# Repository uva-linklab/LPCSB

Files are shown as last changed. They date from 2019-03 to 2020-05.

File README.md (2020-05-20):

# LPCSB
LPCSB = Low Power Color Sensing Board

The LPCSB is designed to measure the ambient light in the surrounding area by means of a TCS34725 Color Sensor.  The sensor uses four analog-to-digital converters (ADCs) to read four photodiodes (one photodiode per ADC).  The photodiodes are red-filtered, green-filtered, blue-filtered, and clear (no filter).  The photodiodes are also covered with an IR-blocking filter.  The code in the "software" folder of this repository is responsible for initializing all of the hardware on the LPCSB, configuring the settings of the color sensor (integration time, gain, enabling the internal oscillator, enabling the ADCs, and setting a hardware interrupt in the sensor), reading and saving the values taken by the four ADCs mentioned previously, and then calculating the the temperature of each color (how much of each is in the sample taken), as well as the lux (intensity per square meter) of said sample.  The measured color temperatures along with the calculated values are broadcast through the BLE radio built into the nrf51822 processor used in this board several times, with new measurements being taken every five seconds.  

There is also a data-processing algorithm that is meant to operate on a desktop computer, using  a Bluetooth receiver - see thesis for the specific one - to capture the transmitted data from the LPCSB and save it to an Excel spreadsheet.  Depending on the version of the algorithm being used, it can also classify the type of light measured by the LPCSB before saving the data to Excel.  When running tests with the LPCSB, make sure that the algorithm is running BEFORE activating the LPCSB to avoid errors with the algorithm in its current state.

SIDE NOTE:  Make sure that the external crystal oscillator meets the BLE chip requirements for the external clock frequency described in the nrf51822 datasheet. In this case, the required frequency for the external clock is 16 MHz.  For some reason, the clock chips that were being used early on were 26 MHz clocks instead of 16 MHz, which WILL cause errors with whichever sections of the processor happen to rely on the external signal (in this case, the BLE Radio parts).

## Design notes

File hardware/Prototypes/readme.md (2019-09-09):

# Version 1:

The files in this folder hold prototype schematics for potential additions for the LPCSB (layout and schematic files).

Label the prototype files as follows: LPCSB_Color_[insert new sensor name here]_[board or schematic]

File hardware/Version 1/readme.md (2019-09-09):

# Version 1:

The files in this folder hold the current hardware schematics for the LPCSB (layout and schematic files).

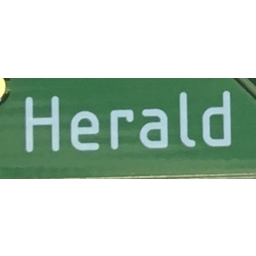
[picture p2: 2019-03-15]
summon/LPCSB/img/herald.png

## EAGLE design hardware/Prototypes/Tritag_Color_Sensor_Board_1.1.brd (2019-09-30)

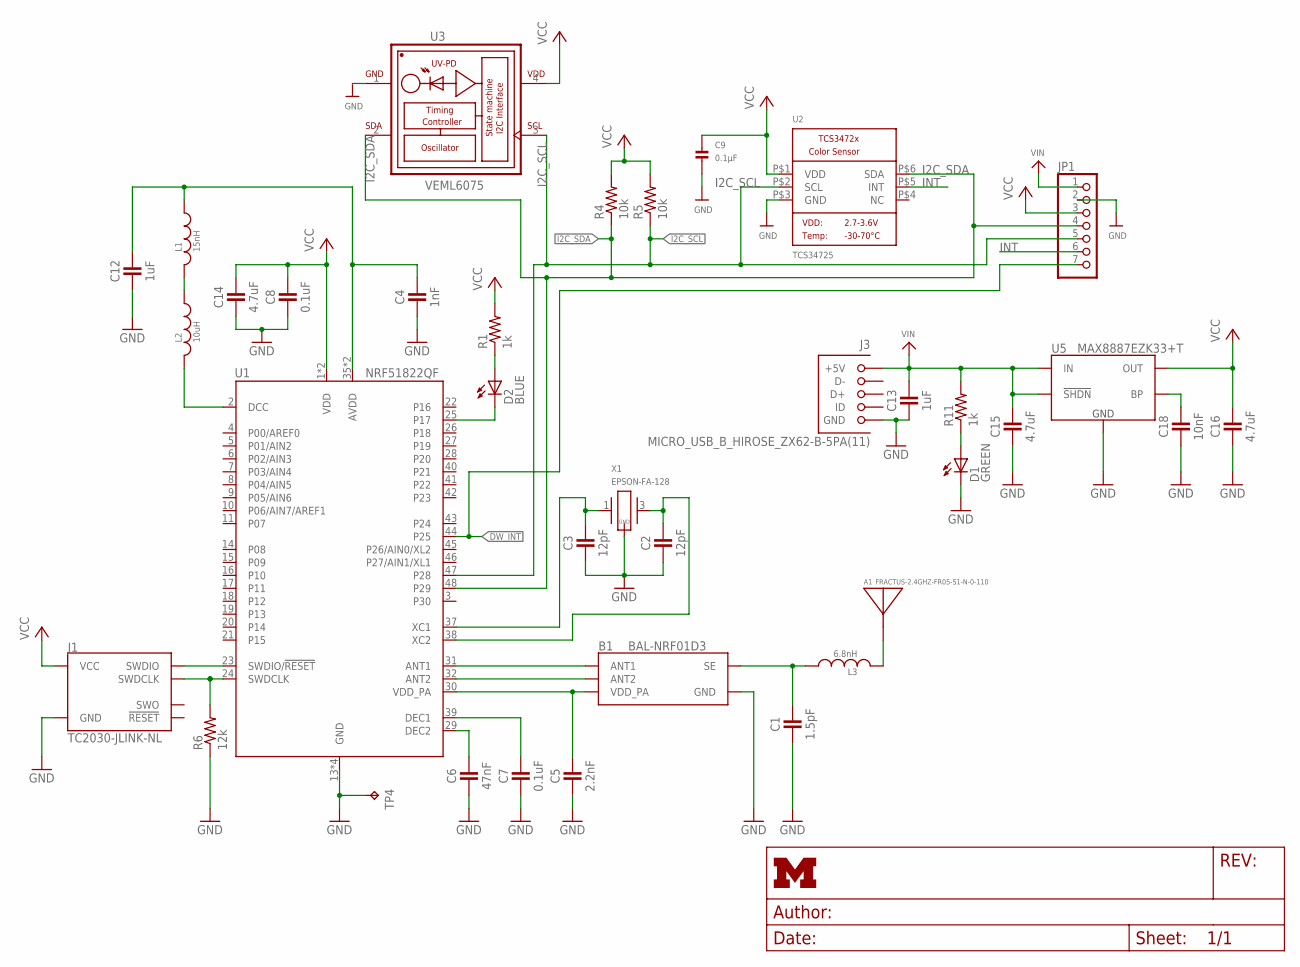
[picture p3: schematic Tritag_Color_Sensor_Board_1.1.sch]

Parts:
A1: FRACTUS-2.4GHZ-FR05-S1-N-0-110; FRACTUS-ANTENNA-FR05-S1-N-0-110
B1: BAL-NRF01D3
C1: 1.5pF; 0402_CAP
C2, C3: 12pF; 0402_CAP
C4: 1nF; 0402_CAP
C5: 2.2nF; 0402_CAP
C6: 47nF; 0402_CAP
C7, C8: 0.1uF; 0402_CAP
C9: 0.1µF; _0805
C12, C13: 1uF; 0402_CAP
C14, C15, C16: 4.7uF; 0402_CAP
C18: 10nF; 0402_CAP
D1: GREEN; LED-0603
D2: BLUE; LED-0603
J1: TC2030-JLINK-NL; TC2030-IDC-NL
J3: MICRO_USB_B_HIROSE_ZX62-B-5PA(11); USB_MICRO_B-HIROSE-ZX62-B-5PA(11)
JP1: HEADER-1X770MIL; 1X07_ROUND_70
L1: 15nH; 0402_CAP
L2: 10uH; 0603_CAP
L3: 6.8nH; 0402_CAP
R1, R11: 1k; 0402_RES
R4, R5: 10k; 0402_RES
R6: 12k; 0402_RES
TP4: TPTP06SQ; TP06SQ
U1: NRF51822QF; QFN-48-6MM
U2: TCS34725; TCS3472_FN6
U3: VEML6075; VISHAY_VEML6075_1.25X2X1
U5: MAX8887EZK33+T; SOT-23-5
X1: EPSON-FA-128; FA-128

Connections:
!CHRG: D1.A, R11.1
!CHRG1: D2.A, R1.1
ANTENNA: A1.ANT, L3.2
AVDD: C4.1, C12.1, L1.1, U1.35 (AVDD), U1.36 (AVDD)
DCC: L2.2, U1.2 (DCC)
DW_INT: JP1.7, U1.44 (P25)
GND: B1.GND, C1.2, C2.2, C3.2, C4.2, C5.2, C6.2, C7.2, C8.2, C9.2, C12.2, C13.2, C14.2, C15.2, C16.2, C18.2, D1.C, J1.5 (GND), J3.5 (GND), JP1.2, R6.1, TP4.TP, U1.13 (GND), U1.33 (GND), U1.34 (GND), U1.GND, U2.P$3 (GND), U3.1 (GND), U5.2 (GND), X1.2 (GND), X1.4 (GND)
I2C_SCL: JP1.5, R5.1, U1.47 (P28), U2.P$2 (SCL), U3.3 (SCL)
I2C_SDA: JP1.4, R4.1, U1.48 (P29), U2.P$6 (SDA), U3.2 (SDA)
INT: JP1.6, U2.P$5 (INT)
unnamed: B1.SE, C1.1, L3.1
unnamed: D2.C, U1.25 (P17)
unnamed: C3.1, U1.37 (XC1), X1.1
unnamed: C2.1, U1.38 (XC2), X1.3 (2)
unnamed: C18.1, U5.4 (BP)
unnamed: C6.1, U1.29 (DEC2)
unnamed: C7.1, U1.39 (DEC1)
unnamed: B1.ANT1, U1.31 (ANT1)
unnamed: B1.ANT2, U1.32 (ANT2)
unnamed: B1.VCC (VDD_PA), C5.1, U1.30 (VDD_PA)
unnamed: L1.2, L2.1
SWDCLK: J1.4 (SWDCLK), R6.2, U1.24 (SWDCLK)
SWDIO/!RESET: J1.2 (SWDIO), U1.23 (SWDIO/!RESET)
VCC: C8.1, C9.1, C14.1, C16.1, J1.1 (VCC), JP1.3, R1.2, R4.2, R5.2, U1.1 (VDD), U1.12 (VDD), U2.P$1 (VDD), U3.4 (VDD), U5.5 (OUT)
VIN: C13.1, C15.1, J3.1 (+5V), JP1.1, R11.2, U5.1 (IN), U5.3 (!SHDN)

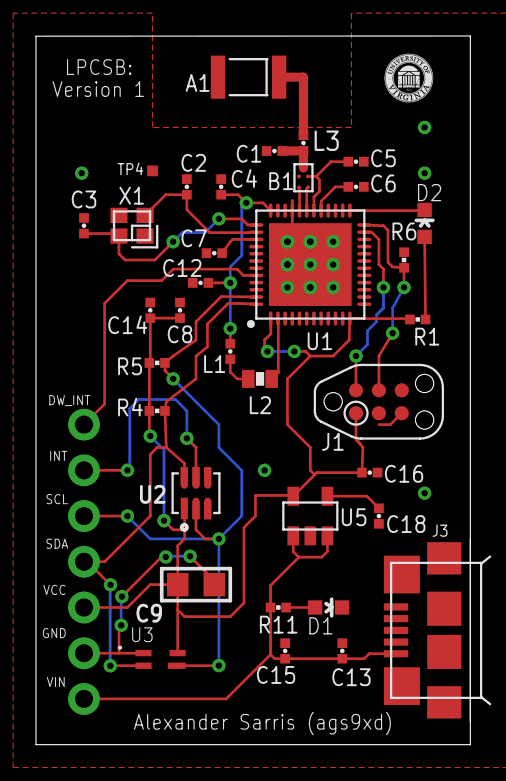
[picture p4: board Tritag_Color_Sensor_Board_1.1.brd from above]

Board: 2 copper layers, 24.1 x 39.4 mm, 36 parts (0 on the bottom side), 25 nets.

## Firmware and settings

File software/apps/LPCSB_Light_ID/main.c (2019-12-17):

/* Send an adv and slowly incorporate color code: LPCSB2 */

//Standard Libraries
#include <stdbool.h>
#include <stdint.h>

//Nordic Libraries
#include "app_error.h"
#include "app_timer.h"
#include "app_twi.h"
#include "ble.h"
#include "ble_debug_assert_handler.h"
// #include "boards.h"
#include "led.h"
#include "nordic_common.h"
#include "nrf_delay.h"
#include "nrf_gpio.h"
#include "nrf.h"
#include "nrf_sdm.h"
#include "softdevice_handler.h"

//Peripherals
#include "ble_advdata.h"
#include "simple_ble.h"
#include "simple_adv.h"
#include "eddystone.h"

//Sensor Library
#include "tcs3472REDO.h"

/*********************/
/***** LED Stuff *****/
/*********************/
#define LED 17

/*********************/
/****  I2C Stuff *****/
/*********************/
#define I2C_SDA_PIN 29
#define I2C_SCL_PIN 28
#define APP_IRQ_PRIORITY_LOW 3
static app_twi_t twi_instance = APP_TWI_INSTANCE(1);

/***********************/
/***** Timer Stuff *****/
/***********************/
//Timer Ticks appears to be in milliseconds
#define STARTUP_DELAY APP_TIMER_TICKS(10, APP_TIMER_PRESCALER)
#define MEASUREMENT_DELAY APP_TIMER_TICKS(5000, APP_TIMER_PRESCALER) //5000 ms delay
#define APP_TIMER_PRESCALER 0
APP_TIMER_DEF(startup_timer);   //APP_TIMER_TICKS converts ms to timer ticks with prescaler
APP_TIMER_DEF(color_timer);
/************************/
/***** Sensor Stuff *****/
/************************/
uint16_t redData;
uint16_t greenData;
uint16_t blueData;
uint16_t colorTempData; //Not used at the moment
uint16_t luxData;

float maxRatio;
float minRatio;
float ratioCompare;

//Sensor values: Can only transmit bytes, not ints
static struct {
    uint8_t sensorID;
    uint8_t clearTempL; //Leftmost byte
    uint8_t clearTempR; //Rightmost byte
    uint8_t redTempL;   //Leftmost byte
    uint8_t redTempR;   //Rightmost byte
    uint8_t greenTempL; //Leftmost byte
    uint8_t greenTempR; //Rightmost byte
    uint8_t blueTempL;  //Leftmost byte
    uint8_t blueTempR;  //Rightmost byte
    uint8_t colorTempL; //Leftmost byte
    uint8_t colorTempR; //Rightmost byte
    uint8_t luxL;       //Leftmost byte
    uint8_t luxR;       //Rightmost byte
    uint8_t packetNumL; //Packet number MSB
    uint8_t packetNumR; //Packet number LSB
} color_sensor_info = {0};

//Identification:
static struct {
    uint8_t sensorID;
    uint8_t LightType;  //Type of light: 0's = Incandescent, 1's = LED, 2's = Fluorescent, 3's = Sunlight, 4's = Unknown
    uint8_t packetNumL; //Packet number MSB
    uint8_t packetNumR; //Packet number LSB
} light_type = {0};

//Configuration indicators
static struct{
    bool intTimeConfigured;
    bool gainConfigured;
    bool sensorEnabled;
    bool adcEnabled;
    bool interruptSet;
} register_configuration = {0};

/*************************************/
/********** BLE Advertising **********/
/*************************************/
#define BLE_ADVERTISING_ENABLED 1
#define DEVICE_NAME             "LPCSB_TEST"
#define COLOR_DATA_URL          "j2x.us/LPCSB"
#define UVA_COMPANY_IDENTIFIER  0x02E0
#define UVA_RAW_COLOR_SERVICE   0x31
#define UVA_LIGHT_COLOR_SERVICE 0x32

uint8_t color_data[1 + sizeof(color_sensor_info)];
uint8_t light_data[1 + sizeof(light_type)];

// Intervals for advertising and connections
static simple_ble_config_t ble_config = {
    .platform_id       = 0x40,              // used as 4th octect in device BLE address
    .device_id         = DEVICE_ID_DEFAULT,
    .adv_name          = DEVICE_NAME,       // used in advertisements if there is room
    .adv_interval      = MSEC_TO_UNITS(2500, UNIT_0_625_MS), //Adv. interval of 5000 ms
    .min_conn_interval = MSEC_TO_UNITS(500, UNIT_1_25_MS),
    .max_conn_interval = MSEC_TO_UNITS(1000, UNIT_1_25_MS)
};

/*************************************/
/******** Function Prototypes ********/
/*************************************/
static void i2c_init (void);
static void start_sensing();
static void finish_reading_ID (int8_t ID);
static void finish_set_int_time();
static void finish_set_gain();
static void finish_sensor_enable();
static void finish_set_interrupt();
static void finish_reading_clear (int16_t clear);
static void finish_reading_red (int16_t red);
static void finish_reading_green (int16_t green);
static void finish_reading_blue (int16_t blue);
static void processData();
static void advertiseData();
static void start_color_measuring();

/*************************************/
/***** Reading and Config Methods ****/
/*************************************/
static void start_color_measuring(){
    tcs34725_read_clear(finish_reading_clear);
}

static void advertiseData(){
    //If the packet number bytes are at their max values:
    if(color_sensor_info.packetNumR >= 255 || light_type.packetNumR >= 255){
        color_sensor_info.packetNumR = 0;   //Reset the color data packet number LSB
        color_sensor_info.packetNumL += 1;  //Increment the color data packet number MSB
        light_type.packetNumR = 0;          //Reset the light type packet number LSB
        light_type.packetNumL += 1;         //Increment the light type packet number MSB
    }
    else{
        color_sensor_info.packetNumR += 1;  //Increment the color data packet number LSB
        color_sensor_info.packetNumL += 0;  //Leave the color data packet number MSB alone
        light_type.packetNumR += 1;         //Increment the light type packet number LSB
        light_type.packetNumL += 0;         //Leave the light type packet number MSB alone
    }

    ble_advdata_manuf_data_t DataSent;

    //Light type identification
    if(redData >= greenData && redData >= blueData && maxRatio >= 1.1 && minRatio <= 1.1){
        light_type.LightType = 0x00; //Incandescent
    }
    else if(ratioCompare <= 1.45 && luxData <= 2000){
        light_type.LightType = 0x11; //LED
    }
    else if(ratioCompare <= 1.7 && luxData >= 2000){
        light_type.LightType = 0x22; //Fluorescent
    }
    // else if(){} //Daylight characteristics haven't been identified yet
    else{
        light_type.LightType = 0x44; //Unknown
    }

    if(light_type.LightType == 0x44){ //If the type of light is unknown. Transmit the raw data
        color_data[0] = UVA_RAW_COLOR_SERVICE;
        memcpy(color_data + 1, &color_sensor_info, sizeof(color_sensor_info));

        DataSent.company_identifier = UVA_COMPANY_IDENTIFIER;
        DataSent.data.p_data = color_data;
        DataSent.data.size = 1 + sizeof(color_data);

        //Flash the LED very quickly 10 times
        for(int i = 0; i < 10; i++){
            led_toggle(LED);
            nrf_delay_ms(50);
            led_toggle(LED);
            nrf_delay_ms(50);
        }
    }
    else{   //The type of light has been identified! Transmit it
        light_data[0] = UVA_LIGHT_COLOR_SERVICE;
        memcpy(light_data + 1, &light_type, sizeof(light_data));

        DataSent.company_identifier = UVA_COMPANY_IDENTIFIER;
        DataSent.data.p_data = light_data;
        DataSent.data.size = 1 + sizeof(light_data);

        //Flash the LED very quickly 10 times
        for(int i = 0; i < 10; i++){
            led_toggle(LED);
            nrf_delay_ms(50);
            led_toggle(LED);
            nrf_delay_ms(250);
        }
    }
    // Advertise name and data
    // simple_adv_only_name();
    simple_adv_manuf_data(&DataSent);
    // eddystone_with_manuf_adv(COLOR_DATA_URL, &DataSent); //Transmit the data
    led_on(LED);
    nrf_delay_ms(1000);
    led_off(LED);

    app_timer_start(color_timer, MEASUREMENT_DELAY, NULL);
}

static void processData(){
redData = color_sensor_info.redTempL;   //Reset the red variable and set equal to redTemp MSB
    redData = redData << 8;                 //Shift the bits to the left by 8
    redData |= color_sensor_info.redTempR;  //Or the result with redTemp LSB

    greenData = color_sensor_info.greenTempL;   //Reset the green variable and set equal to greenTemp MSB
    greenData = greenData << 8;                 //Shift the bits to the left by 8
    greenData |= color_sensor_info.greenTempR;  //Or the result with greenTemp LSB

    blueData = color_sensor_info.blueTempL;   //Reset the blue variable and set equal to blueTemp MSB
    blueData = blueData << 8;                 //Shift the bits to the left by 8
    blueData |= color_sensor_info.blueTempR;  //Or the result with blueTemp LSB

    colorTempData = color_sensor_info.colorTempL;   //Reset the colorTemp variable and set equal to colorTemp MSB
    colorTempData = colorTempData << 8;             //Shift the bits to the left by 8
    colorTempData |= color_sensor_info.colorTempR;  //Or the result with colorTemp LSB

    luxData = color_sensor_info.luxL;   //Reset the colorTemp variable and set equal to colorTemp MSB
    luxData = luxData << 8;             //Shift the bits to the left by 8
    luxData |= color_sensor_info.luxR;  //Or the result with colorTemp LSB

    maxRatio = 0.0;
    minRatio = 0.0;
    ratioCompare = 0.0;

    if(redData >= greenData && redData >= blueData){    //If red is greater than or equal to green and blue:
        if(greenData >= blueData){
            maxRatio = 1.0 * (float)redData / (float)greenData;
            minRatio = 1.0 * (float)greenData / (float)blueData;
        }
        else{
            maxRatio = 1.0 * (float)redData / (float)blueData;
            minRatio = 1.0 * (float)blueData / (float)greenData;
        }
    }
    else if(greenData >= blueData && greenData >= redData){ //If green is greater than or equal to blue and red:
        if(blueData >= redData){
            maxRatio = 1.0 * (float)greenData / (float)blueData;
            minRatio = 1.0 * (float)blueData / (float)redData;
        }
        else{
            maxRatio = 1.0 * (float)greenData / (float)redData;
            minRatio = 1.0 * (float)redData / (float)blueData;
        }
    }
    else if(blueData >= redData && blueData >= greenData){  //If blue is greater than or equal to red and green:
        if(redData >= greenData){
            maxRatio = 1.0 * (float)blueData / (float)redData;
            minRatio = 1.0 * (float)redData / (float)greenData;
        }
        else{
            maxRatio = 1.0 * (float)blueData / (float)greenData;
            minRatio = 1.0 * (float)greenData / (float)redData;
        }
    }

    if(maxRatio >= minRatio){
        ratioCompare = maxRatio / minRatio;
    }
    else{
        ratioCompare = minRatio / maxRatio;
    }

    advertiseData();
}

static void finish_reading_blue (int16_t blue){
    color_sensor_info.blueTempL = (blue >> 8);
    color_sensor_info.blueTempR = (blue & 0xFF);
    color_sensor_info.colorTempL = (tcs34725_calculate_color_temperature() >> 8);
    color_sensor_info.colorTempR = (tcs34725_calculate_color_temperature() & 0xFF);
    color_sensor_info.luxL = (tcs34725_calculate_lux() >> 8);
    color_sensor_info.luxR = (tcs34725_calculate_lux() & 0xFF);

    processData();
}

static void finish_reading_green (int16_t green){
    color_sensor_info.greenTempL = (green >> 8);
    color_sensor_info.greenTempR = (green & 0xFF);
    tcs34725_read_blue(finish_reading_blue);        //Read the blue-filter photodiode
}

static void finish_reading_red (int16_t red){
    color_sensor_info.redTempL = (red >> 8);
    color_sensor_info.redTempR = (red & 0xFF);

    tcs34725_read_green(finish_reading_green);      //Read the green-filter photodiode

}

static void finish_reading_clear (int16_t clear){
    color_sensor_info.clearTempL = (clear >> 8);
    color_sensor_info.clearTempR = (clear & 0xFF);

    tcs34725_read_red(finish_reading_red);          //Read the red-filter photodiode

}

static void finish_set_interrupt(){

    register_configuration.interruptSet = true;
    tcs34725_read_clear(finish_reading_clear);      //Read the clear-filter photodiode
}

static void finish_adc_enable(){
    register_configuration.adcEnabled = true;

    //Note: for some reason we need both this AND the C-file timer values...
    nrf_delay_ms(700);

    tcs34725_read_clear(finish_reading_clear);      //Read the clear-filter photodiode
}

static void finish_sensor_enable(){
    register_configuration.sensorEnabled = true;
    nrf_delay_ms(3);  
    tcs34725_adc_enable(finish_adc_enable);         //Enable the ADC
}

static void finish_set_gain(){
    register_configuration.gainConfigured = true;
    tcs34725_sensor_enable(finish_sensor_enable);   //Enable the internal oscillator
}

static void finish_set_int_time(){
    register_configuration.intTimeConfigured = true;
    tcs34725_Set_Gain(finish_set_gain);             //Set the gain
}

static void finish_reading_ID (int8_t ID){
    color_sensor_info.sensorID = ID;
    light_type.sensorID = ID;
    tcs34725_Set_Int_Time(finish_set_int_time);     //Set the integration time
}

//Initialize the TWI bus (I2C bus)
static void i2c_init (void) {
    // Initialize the I2C module
    nrf_drv_twi_config_t twi_config;
    twi_config.sda               = I2C_SDA_PIN;
    twi_config.scl                = I2C_SCL_PIN;
    twi_config.frequency          = NRF_TWI_FREQ_100K;
    twi_config.interrupt_priority = APP_IRQ_PRIORITY_LOW;

    //XXX: 8 is arbitrary!!
    uint32_t err_code;
    APP_TWI_INIT(&twi_instance, &twi_config, 8, err_code);
    APP_ERROR_CHECK(err_code);
}

// Set up the sensor configurations and start sampling
static void start_sensing () {
    tcs34725_init(&twi_instance);           //Initialize the sensor
    tcs34725_read_ID(finish_reading_ID);    //Read the ID of the sensor (to check connection)
}

int main(void) {
    uint32_t err_code;

    /* All methods are bracketed by an LED turning on and 
     * off to show that the method has been initialized. */

    /* Initialize the LED for the BLE */
    led_init(LED);
    led_off(LED);

    //Reset the packet number for the color sensor data
    color_sensor_info.packetNumL = 0;
    color_sensor_info.packetNumR = 0;
    light_type.packetNumL = 0;
    light_type.packetNumR = 0;

    // Setup BLE (this also inits the timer AND softdevice libraries)
    led_on(LED);
    nrf_delay_ms(1000);
    simple_ble_init(&ble_config);
    led_off(LED);
    nrf_delay_ms(1000);

    //Initialize the I2C channels
    led_on(LED);
    nrf_delay_ms(1000);
    i2c_init();
    led_off(LED);
    nrf_delay_ms(1000);

    //Create the timers
    led_on(LED);
    nrf_delay_ms(1000);
    app_timer_create(&startup_timer, APP_TIMER_MODE_SINGLE_SHOT, start_sensing);
    app_timer_create(&color_timer, APP_TIMER_MODE_SINGLE_SHOT, start_color_measuring);
    led_off(LED);
    nrf_delay_ms(1000);

    //Start and run this timer for STARTUP_DELAY milliseconds
    app_timer_start(startup_timer, STARTUP_DELAY, NULL);

    while (1) {
        power_manage();
    }
}

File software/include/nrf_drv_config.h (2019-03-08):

/* Copyright (c) 2015 Nordic Semiconductor. All Rights Reserved.
 *
 * The information contained herein is property of Nordic Semiconductor ASA.
 * Terms and conditions of usage are described in detail in NORDIC
 * SEMICONDUCTOR STANDARD SOFTWARE LICENSE AGREEMENT.
 *
 * Licensees are granted free, non-transferable use of the information. NO
 * WARRANTY of ANY KIND is provided. This heading must NOT be removed from
 * the file.
 *
 */

#ifndef NRF_DRV_CONFIG_H
#define NRF_DRV_CONFIG_H

/**
 * Provide a non-zero value here in applications that need to use several
 * peripherals with the same ID that are sharing certain resources
 * (for example, SPI0 and TWI0). Obviously, such peripherals cannot be used
 * simultaneously. Therefore, this definition allows to initialize the driver
 * for another peripheral from a given group only after the previously used one
 * is uninitialized. Normally, this is not possible, because interrupt handlers
 * are implemented in individual drivers.
 * This functionality requires a more complicated interrupt handling and driver
 * initialization, hence it is not always desirable to use it.
 */
#define PERIPHERAL_RESOURCE_SHARING_ENABLED  0

/* CLOCK */
#define CLOCK_ENABLED 0

#if (CLOCK_ENABLED == 1)
#define CLOCK_CONFIG_XTAL_FREQ          NRF_CLOCK_XTALFREQ_Default
#define CLOCK_CONFIG_LF_SRC             NRF_CLOCK_LF_SRC_Xtal
#define CLOCK_CONFIG_IRQ_PRIORITY       APP_IRQ_PRIORITY_LOW
#endif

/* GPIOTE */
#define GPIOTE_ENABLED 0

#if (GPIOTE_ENABLED == 1)
#define GPIOTE_CONFIG_USE_SWI_EGU false
#define GPIOTE_CONFIG_IRQ_PRIORITY APP_IRQ_PRIORITY_LOW
#define GPIOTE_CONFIG_NUM_OF_LOW_POWER_EVENTS 1
#endif

/* TIMER */
#define TIMER0_ENABLED 0

#if (TIMER0_ENABLED == 1)
#define TIMER0_CONFIG_FREQUENCY    NRF_TIMER_FREQ_16MHz
#define TIMER0_CONFIG_MODE         TIMER_MODE_MODE_Timer
#define TIMER0_CONFIG_BIT_WIDTH    TIMER_BITMODE_BITMODE_32Bit
#define TIMER0_CONFIG_IRQ_PRIORITY APP_IRQ_PRIORITY_LOW

#define TIMER0_INSTANCE_INDEX      0
#endif

#define TIMER1_ENABLED 0

#if (TIMER1_ENABLED == 1)
#define TIMER1_CONFIG_FREQUENCY    NRF_TIMER_FREQ_16MHz
#define TIMER1_CONFIG_MODE         TIMER_MODE_MODE_Timer
#define TIMER1_CONFIG_BIT_WIDTH    TIMER_BITMODE_BITMODE_16Bit
#define TIMER1_CONFIG_IRQ_PRIORITY APP_IRQ_PRIORITY_LOW

#define TIMER1_INSTANCE_INDEX      (TIMER0_ENABLED)
#endif

#define TIMER2_ENABLED 0

#if (TIMER2_ENABLED == 1)
#define TIMER2_CONFIG_FREQUENCY    NRF_TIMER_FREQ_16MHz
#define TIMER2_CONFIG_MODE         TIMER_MODE_MODE_Timer
#define TIMER2_CONFIG_BIT_WIDTH    TIMER_BITMODE_BITMODE_16Bit
#define TIMER2_CONFIG_IRQ_PRIORITY APP_IRQ_PRIORITY_LOW

#define TIMER2_INSTANCE_INDEX      (TIMER1_ENABLED+TIMER0_ENABLED)
#endif

#define TIMER3_ENABLED 0

#if (TIMER3_ENABLED == 1)
#define TIMER3_CONFIG_FREQUENCY    NRF_TIMER_FREQ_16MHz
#define TIMER3_CONFIG_MODE         TIMER_MODE_MODE_Timer
#define TIMER3_CONFIG_BIT_WIDTH    TIMER_BITMODE_BITMODE_16Bit
#define TIMER3_CONFIG_IRQ_PRIORITY APP_IRQ_PRIORITY_LOW

#define TIMER3_INSTANCE_INDEX      (TIMER2_ENABLED+TIMER1_ENABLED+TIMER0_ENABLED)
#endif

#define TIMER4_ENABLED 0

#if (TIMER4_ENABLED == 1)
#define TIMER4_CONFIG_FREQUENCY    NRF_TIMER_FREQ_16MHz
#define TIMER4_CONFIG_MODE         TIMER_MODE_MODE_Timer
#define TIMER4_CONFIG_BIT_WIDTH    TIMER_BITMODE_BITMODE_16Bit
#define TIMER4_CONFIG_IRQ_PRIORITY APP_IRQ_PRIORITY_LOW

#define TIMER4_INSTANCE_INDEX      (TIMER3_ENABLED+TIMER2_ENABLED+TIMER1_ENABLED+TIMER0_ENABLED)
#endif


#define TIMER_COUNT (TIMER0_ENABLED + TIMER1_ENABLED + TIMER2_ENABLED + TIMER3_ENABLED + TIMER4_ENABLED)

/* RTC */
#define RTC0_ENABLED 0

#if (RTC0_ENABLED == 1)
#define RTC0_CONFIG_FREQUENCY    32678
#define RTC0_CONFIG_IRQ_PRIORITY APP_IRQ_PRIORITY_LOW
#define RTC0_CONFIG_RELIABLE     false

#define RTC0_INSTANCE_INDEX      0
#endif

#define RTC1_ENABLED 0

#if (RTC1_ENABLED == 1)
#define RTC1_CONFIG_FREQUENCY    32768
#define RTC1_CONFIG_IRQ_PRIORITY APP_IRQ_PRIORITY_LOW
#define RTC1_CONFIG_RELIABLE     false

#define RTC1_INSTANCE_INDEX      (RTC0_ENABLED)
#endif

#define RTC_COUNT                (RTC0_ENABLED+RTC1_ENABLED)

#define NRF_MAXIMUM_LATENCY_US 2000

/* RNG */
#define RNG_ENABLED 0

#if (RNG_ENABLED == 1)
#define RNG_CONFIG_ERROR_CORRECTION true
#define RNG_CONFIG_POOL_SIZE        8
#define RNG_CONFIG_IRQ_PRIORITY     APP_IRQ_PRIORITY_LOW
#endif

/* PWM */

#define PWM0_ENABLED 0

#if (PWM0_ENABLED == 1)
#define PWM0_CONFIG_OUT0_PIN        2
#define PWM0_CONFIG_OUT1_PIN        3
#define PWM0_CONFIG_OUT2_PIN        4
#define PWM0_CONFIG_OUT3_PIN        5
#define PWM0_CONFIG_IRQ_PRIORITY    APP_IRQ_PRIORITY_LOW
#define PWM0_CONFIG_BASE_CLOCK      NRF_PWM_CLK_1MHz
#define PWM0_CONFIG_COUNT_MODE      NRF_PWM_MODE_UP
#define PWM0_CONFIG_TOP_VALUE       1000
#define PWM0_CONFIG_LOAD_MODE       NRF_PWM_LOAD_COMMON
#define PWM0_CONFIG_STEP_MODE       NRF_PWM_STEP_AUTO

#define PWM0_INSTANCE_INDEX 0
#endif

#define PWM1_ENABLED 0
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

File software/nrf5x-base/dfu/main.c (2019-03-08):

/* Copyright (c) 2013 Nordic Semiconductor. All Rights Reserved.
 *
 * The information contained herein is property of Nordic Semiconductor ASA.
 * Terms and conditions of usage are described in detail in NORDIC
 * SEMICONDUCTOR STANDARD SOFTWARE LICENSE AGREEMENT.
 *
 * Licensees are granted free, non-transferable use of the information. NO
 * WARRANTY of ANY KIND is provided. This heading must NOT be removed from
 * the file.
 *
 */

/**@file
 *
 * @defgroup ble_sdk_app_bootloader_main main.c
 * @{
 * @ingroup dfu_bootloader_api
 * @brief Bootloader project main file.
 *
 * -# Receive start data packet.
 * -# Based on start packet, prepare NVM area to store received data.
 * -# Receive data packet.
 * -# Validate data packet.
 * -# Write Data packet to NVM.
 * -# If not finished - Wait for next packet.
 * -# Receive stop data packet.
 * -# Activate Image, boot application.
 *
 */
#include "bootloader.h"
#include "bootloader_util.h"
#include "bootloader_settings.h"
#include <stdint.h>
#include <string.h>
#include <stddef.h>
#include "nordic_common.h"
#include "nrf.h"
#include "nrf_delay.h"
#include "nrf_soc.h"
#include "app_error.h"
#include "nrf_gpio.h"
#include "nrf51_bitfields.h"
#include "ble.h"
#include "nrf51.h"
#include "ble_hci.h"
#include "app_scheduler.h"
#include "app_timer_appsh.h"
#include "nrf_error.h"
#include "softdevice_handler_appsh.h"
#include "pstorage_platform.h"
#include "nrf_mbr.h"
#include "boards.h"

// #if BUTTONS_NUMBER < 1
// #error "Not enough buttons on board"
// #endif

// #if LEDS_NUMBER < 1
// #error "Not enough LEDs on board"
// #endif

#define IS_SRVC_CHANGED_CHARACT_PRESENT 1                                                       /**< Include the service_changed characteristic. For DFU this should normally be the case. */

// #define BOOTLOADER_BUTTON               BSP_BUTTON_3                                         /**< Button used to enter SW update mode. */
#define UPDATE_IN_PROGRESS_LED          ERROR_LED                                                      /**< Led used to indicate that DFU is active. */

#define APP_TIMER_PRESCALER             0                                                       /**< Value of the RTC1 PRESCALER register. */

#define APP_TIMER_OP_QUEUE_SIZE         4                                                       /**< Size of timer operation queues. */

#define BUTTON_DETECTION_DELAY          APP_TIMER_TICKS(50, APP_TIMER_PRESCALER)                /**< Delay from a GPIOTE event until a button is reported as pushed (in number of timer ticks). */

#define SCHED_MAX_EVENT_DATA_SIZE       MAX(APP_TIMER_SCHED_EVT_SIZE, 0)                        /**< Maximum size of scheduler events. */

#define SCHED_QUEUE_SIZE                20                                                      /**< Maximum number of events in the scheduler queue. */

//static const uint8_t ble_addr[6] __attribute__ ((section(".noInit")));
#define BOOTLOADER_BLE_ADDR_START 0x20007F80

#ifndef SOFTDEVICE_s130
void app_error_handler(uint32_t error_code, uint32_t line_num, const uint8_t * p_file_name) {
#else
void app_error_fault_handler(uint32_t error_code, uint32_t line_num, uint32_t info) {
#endif
  nrf_gpio_pin_clear(UPDATE_IN_PROGRESS_LED);
  while(1) {
    nrf_gpio_pin_clear(UPDATE_IN_PROGRESS_LED);
    nrf_delay_ms(100);
    nrf_gpio_pin_set(UPDATE_IN_PROGRESS_LED);
    nrf_delay_ms(100);
  };
}

/**@brief Callback function for asserts in the SoftDevice.
 *
 * @details This function will be called in case of an assert in the SoftDevice.
 *
 * @warning This handler is an example only and does not fit a final product. You need to analyze
 *          how your product is supposed to react in case of Assert.
 * @warning On assert from the SoftDevice, the system can only recover on reset.
 *
 * @param[in] line_num    Line number of the failing ASSERT call.
 * @param[in] file_name   File name of the failing ASSERT call.
 */
void assert_nrf_callback(uint16_t line_num, const uint8_t * p_file_name)
{
#ifndef SOFTDEVICE_s130
    app_error_handler(0xDEADBEEF, line_num, p_file_name);
#else
    app_error_fault_handler(0xDEADBEEF, line_num, 0);
#endif
}


/**@brief Function for initialization of LEDs.
 */
static void leds_init(void)
{
    nrf_gpio_cfg_output(UPDATE_IN_PROGRESS_LED);
    nrf_gpio_pin_set(UPDATE_IN_PROGRESS_LED);
}


/**@brief Function for initializing the timer handler module (app_timer).
 */
static void timers_init(void)
{
    // Initialize timer module, making it use the scheduler.
    APP_TIMER_APPSH_INIT(APP_TIMER_PRESCALER, APP_TIMER_OP_QUEUE_SIZE, true);
}


/**@brief Function for initializing the button module.
 */
static void buttons_init(void)
{
    // nrf_gpio_cfg_sense_input(BOOTLOADER_BUTTON,
    //                          BUTTON_PULL,
    //                          NRF_GPIO_PIN_SENSE_LOW);

}


/**@brief Function for dispatching a BLE stack event to all modules with a BLE stack event handler.
 *
 * @details This function is called from the scheduler in the main loop after a BLE stack
 *          event has been received.
 *
 * @param[in]   p_ble_evt   Bluetooth stack event.
 */
static void sys_evt_dispatch(uint32_t event)
{
    pstorage_sys_event_handler(event);
}


/**@brief Function for initializing the BLE stack.
 *
 * @details Initializes the SoftDevice and the BLE event interrupt.
 *
 * @param[in] init_softdevice  true if SoftDevice should be initialized. The SoftDevice must only
 *                             be initialized if a chip reset has occured. Soft reset from
 *                             application must not reinitialize the SoftDevice.
 */
static void ble_stack_init(bool init_softdevice)
{
    uint32_t         err_code;
    const uint8_t*   _ble_addr;
    sd_mbr_command_t com = {SD_MBR_COMMAND_INIT_SD, };

    if (init_softdevice)
    {
        err_code = sd_mbr_command(&com);
        APP_ERROR_CHECK(err_code);
    }

    err_code = sd_softdevice_vector_table_base_set(BOOTLOADER_REGION_START);
    APP_ERROR_CHECK(err_code);
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

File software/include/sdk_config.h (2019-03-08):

#ifndef SDK_CONFIG_H
#define SDK_CONFIG_H
// <<< Use Configuration Wizard in Context Menu >>>\n
#ifdef USE_APP_CONFIG
#include "app_config.h"
#endif
// <h> nRF_BLE

//==========================================================
// <q> BLE_ADVERTISING_ENABLED  - ble_advertising - Advertising module


#ifndef BLE_ADVERTISING_ENABLED
#define BLE_ADVERTISING_ENABLED 1
#endif

// <q> BLE_DTM_ENABLED  - ble_dtm - Module for testing RF/PHY using DTM commands


#ifndef BLE_DTM_ENABLED
#define BLE_DTM_ENABLED 0
#endif

// <q> BLE_RACP_ENABLED  - ble_racp - Record Access Control Point library


#ifndef BLE_RACP_ENABLED
#define BLE_RACP_ENABLED 0
#endif

// <q> NRF_BLE_QWR_ENABLED  - nrf_ble_qwr - Queued writes support module (prepare/execute write)


#ifndef NRF_BLE_QWR_ENABLED
#define NRF_BLE_QWR_ENABLED 0
#endif

// <q> PEER_MANAGER_ENABLED  - peer_manager - Peer Manager


#ifndef PEER_MANAGER_ENABLED
#define PEER_MANAGER_ENABLED 0
#endif

// </h>
//==========================================================

// <h> nRF_BLE_Services

//==========================================================
// <q> BLE_ANCS_C_ENABLED  - ble_ancs_c - Apple Notification Service Client


#ifndef BLE_ANCS_C_ENABLED
#define BLE_ANCS_C_ENABLED 0
#endif

// <q> BLE_ANS_C_ENABLED  - ble_ans_c - Alert Notification Service Client


#ifndef BLE_ANS_C_ENABLED
#define BLE_ANS_C_ENABLED 0
#endif

// <q> BLE_BAS_C_ENABLED  - ble_bas_c - Battery Service Client


#ifndef BLE_BAS_C_ENABLED
#define BLE_BAS_C_ENABLED 0
#endif

// <q> BLE_BAS_ENABLED  - ble_bas - Battery Service


#ifndef BLE_BAS_ENABLED
#define BLE_BAS_ENABLED 0
#endif

// <q> BLE_CSCS_ENABLED  - ble_cscs - Cycling Speed and Cadence Service


#ifndef BLE_CSCS_ENABLED
#define BLE_CSCS_ENABLED 0
#endif

// <q> BLE_CTS_C_ENABLED  - ble_cts_c - Current Time Service Client


#ifndef BLE_CTS_C_ENABLED
#define BLE_CTS_C_ENABLED 0
#endif

// <q> BLE_DIS_ENABLED  - ble_dis - Device Information Service


#ifndef BLE_DIS_ENABLED
#define BLE_DIS_ENABLED 0
#endif

// <q> BLE_GLS_ENABLED  - ble_gls - Glucose Service


#ifndef BLE_GLS_ENABLED
#define BLE_GLS_ENABLED 0
#endif

// <q> BLE_HIDS_ENABLED  - ble_hids - Human Interface Device Service


#ifndef BLE_HIDS_ENABLED
#define BLE_HIDS_ENABLED 0
#endif

// <e> BLE_HRS_C_ENABLED - ble_hrs_c - Heart Rate Service Client
//==========================================================
#ifndef BLE_HRS_C_ENABLED
#define BLE_HRS_C_ENABLED 0
#endif
#if  BLE_HRS_C_ENABLED
// <o> BLE_HRS_C_RR_INTERVALS_MAX_CNT - Maximum number of RR_INTERVALS per notification to be decoded
#ifndef BLE_HRS_C_RR_INTERVALS_MAX_CNT
#define BLE_HRS_C_RR_INTERVALS_MAX_CNT 30
#endif

#endif //BLE_HRS_C_ENABLED
// </e>

// <q> BLE_HRS_ENABLED  - ble_hrs - Heart Rate Service


#ifndef BLE_HRS_ENABLED
#define BLE_HRS_ENABLED 0
#endif

// <q> BLE_HTS_ENABLED  - ble_hts - Health Thermometer Service


#ifndef BLE_HTS_ENABLED
#define BLE_HTS_ENABLED 0
#endif

// <q> BLE_IAS_C_ENABLED  - ble_ias_c - Immediate Alert Service Client


#ifndef BLE_IAS_C_ENABLED
#define BLE_IAS_C_ENABLED 0
#endif

// <q> BLE_IAS_ENABLED  - ble_ias - Immediate Alert Service


#ifndef BLE_IAS_ENABLED
#define BLE_IAS_ENABLED 0
#endif

// <q> BLE_LBS_C_ENABLED  - ble_lbs_c - Nordic LED Button Service Client


#ifndef BLE_LBS_C_ENABLED
#define BLE_LBS_C_ENABLED 0
#endif

// <q> BLE_LBS_ENABLED  - ble_lbs - LED Button Service


#ifndef BLE_LBS_ENABLED
#define BLE_LBS_ENABLED 0
#endif

// <q> BLE_LLS_ENABLED  - ble_lls - Link Loss Service


#ifndef BLE_LLS_ENABLED
#define BLE_LLS_ENABLED 0
#endif

// <q> BLE_NUS_C_ENABLED  - ble_nus_c - Nordic UART Central Service


#ifndef BLE_NUS_C_ENABLED
#define BLE_NUS_C_ENABLED 0
#endif

// <q> BLE_NUS_ENABLED  - ble_nus - Nordic UART Service


#ifndef BLE_NUS_ENABLED
#define BLE_NUS_ENABLED 0
#endif

// <q> BLE_RSCS_C_ENABLED  - ble_rscs_c - Running Speed and Cadence Client


#ifndef BLE_RSCS_C_ENABLED
#define BLE_RSCS_C_ENABLED 0
#endif

// <q> BLE_RSCS_ENABLED  - ble_rscs - Running Speed and Cadence Service


#ifndef BLE_RSCS_ENABLED
#define BLE_RSCS_ENABLED 0
#endif

// <q> BLE_TPS_ENABLED  - ble_tps - TX Power Service


#ifndef BLE_TPS_ENABLED
#define BLE_TPS_ENABLED 0
#endif

// </h>
//==========================================================

// <h> nRF_Drivers

//==========================================================
// <e> ADC_ENABLED - nrf_drv_adc - Driver for ADC peripheral (nRF51)
//==========================================================
#ifndef ADC_ENABLED
#define ADC_ENABLED 0
#endif
#if  ADC_ENABLED
// <o> ADC_CONFIG_IRQ_PRIORITY  - Interrupt priority


// <i> Priorities 0,2 (nRF51) and 0,1,4,5 (nRF52) are reserved for SoftDevice
// <0=> 0 (highest)
// <1=> 1
// <2=> 2
// <3=> 3

#ifndef ADC_CONFIG_IRQ_PRIORITY
#define ADC_CONFIG_IRQ_PRIORITY 3
#endif
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

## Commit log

2018-11-24 Need to add final methods
    All necessary methods for configuring the sensor and reading color values are up and running. Need to uncomment and test the methods for calculating color temperature and lux. Also need to write and 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
2019-02-28 Update Files
    The board is now able to read the sensor once and broadcast the data
2019-03-08 Adding Full Code
    Board is set to broadcast data once over every five seconds with "simple" and "eddystone" Bluetooth libraries. Am currently working on the HTML file for the web page to display the data sent through 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
2019-07-08 Update main.c
    Added sequence number between sensorID and color data
2019-09-09 Adding PCB Files
    [Tritag_Color_Sensor_Board.brd, Tritag_Color_Sensor_Board.sch]
2019-09-09 Add PCB gerber files
2019-09-09 Update board files
    [Tritag_Color_Sensor_Board.brd, Tritag_Color_Sensor_Board.sch]
2019-09-30 New prototype with VEML6075 UV sensor
    [Tritag_Color_Sensor_Board_1.1.brd, Tritag_Color_Sensor_Board_1.1.sch]
2019-12-17 Updates
    Added an app that will ID the type of light on the PCB and updated the original app

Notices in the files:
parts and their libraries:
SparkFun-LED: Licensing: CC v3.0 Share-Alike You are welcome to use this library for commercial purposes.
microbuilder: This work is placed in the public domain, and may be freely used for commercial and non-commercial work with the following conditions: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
